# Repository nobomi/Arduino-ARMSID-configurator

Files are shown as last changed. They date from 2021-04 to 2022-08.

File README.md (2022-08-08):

# Arduino ARMSID configurator

Simple Arduino shield with a sketch for ARMSID and ARM2SID configuration using Tera Term or similar ANSI terminal program. It allows:

- configure ARMSID or ARM2SID parameters (SID type, address mappings, filters, digifix, ...)
- update ARMSID or ARM2SID firmware
- play some SIDs to a 3.5 mm stereo audio jack (more than 60 ohms headphones or line input connection only)

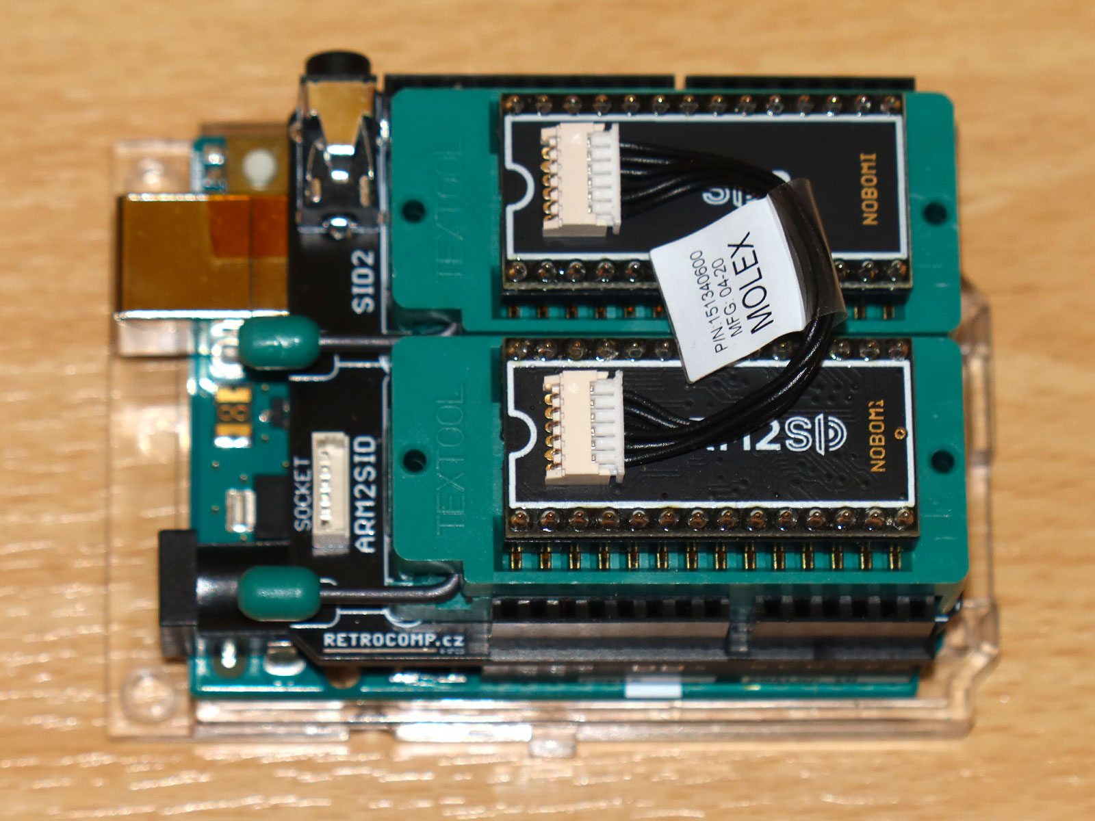
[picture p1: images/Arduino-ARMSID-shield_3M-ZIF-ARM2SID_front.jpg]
Arduino ARMSID configurator shield with 3M ZIF sockets
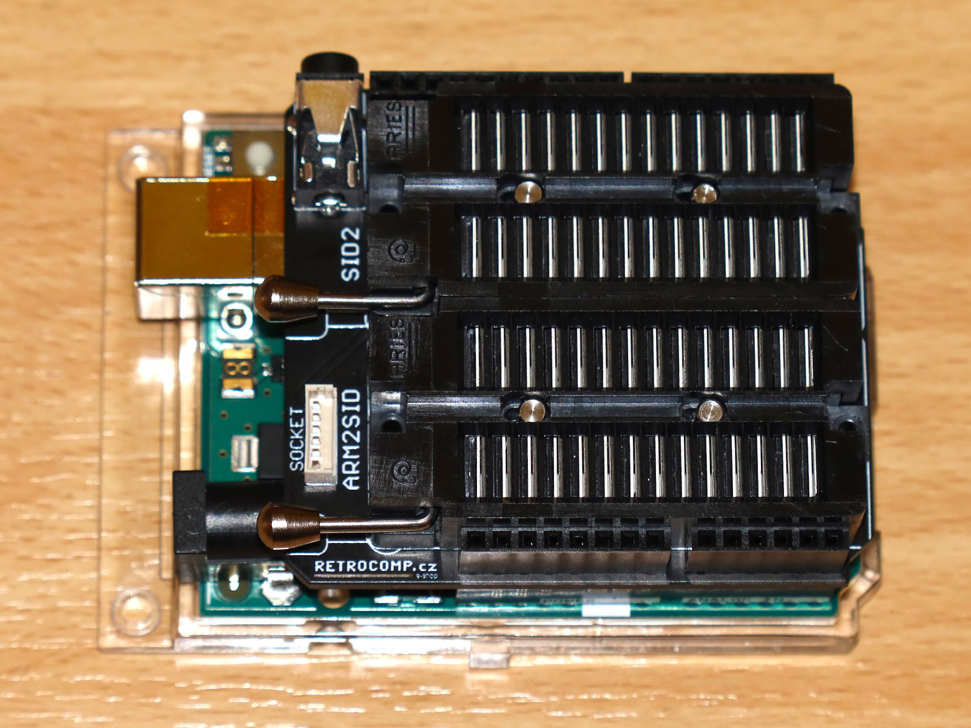
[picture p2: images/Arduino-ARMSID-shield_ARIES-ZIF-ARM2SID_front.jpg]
Arduino ARMSID configurator shield with ARIES ZIF sockets
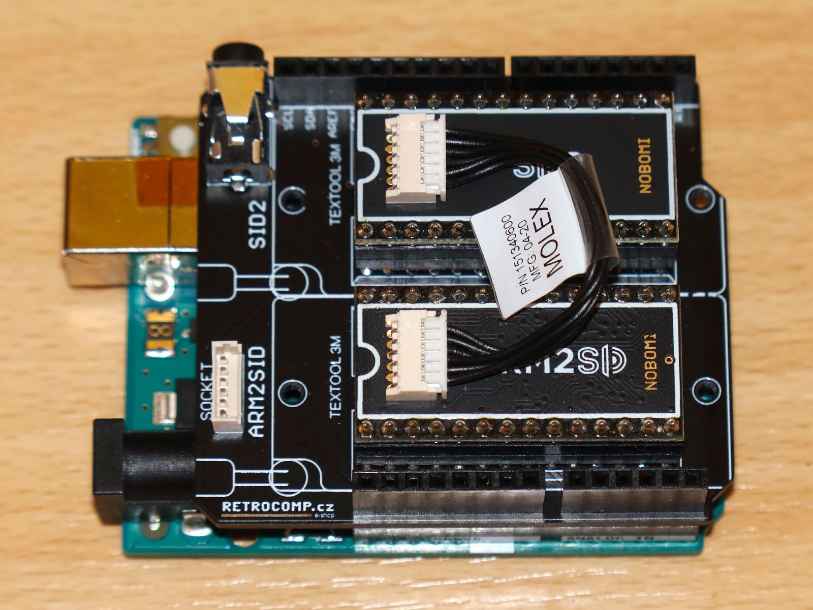
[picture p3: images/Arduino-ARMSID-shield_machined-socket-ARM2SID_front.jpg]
Arduino ARMSID configurator shield with machined sockets
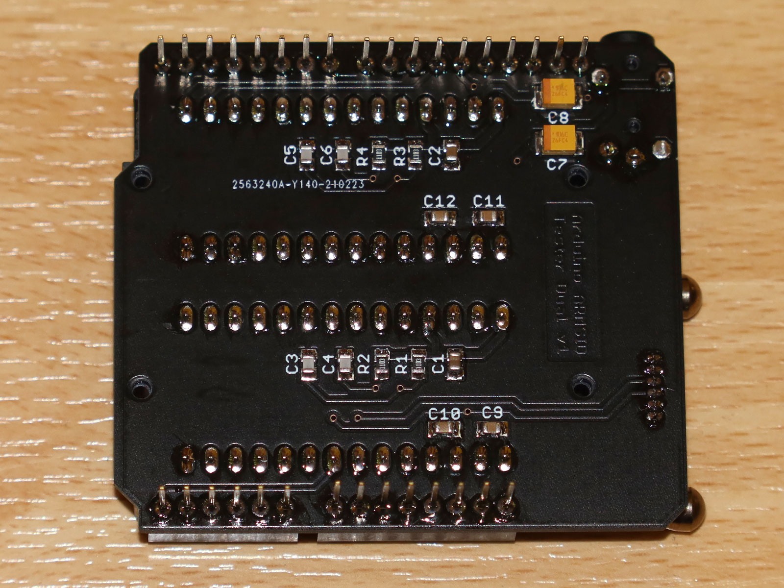
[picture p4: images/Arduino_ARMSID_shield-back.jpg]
Arduino ARMSID configurator shield from back side
&nbsp;&nbsp;&nbsp;&nbsp;&nbsp;&nbsp;

#### ANSI terminal (Tera Term) configuration screen samples

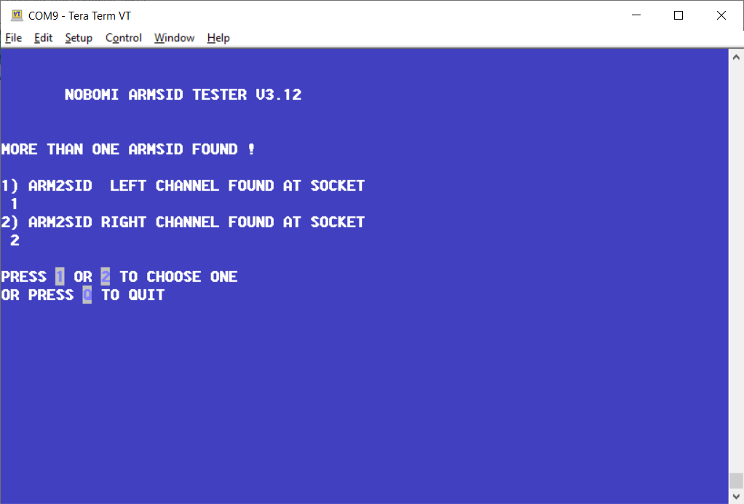
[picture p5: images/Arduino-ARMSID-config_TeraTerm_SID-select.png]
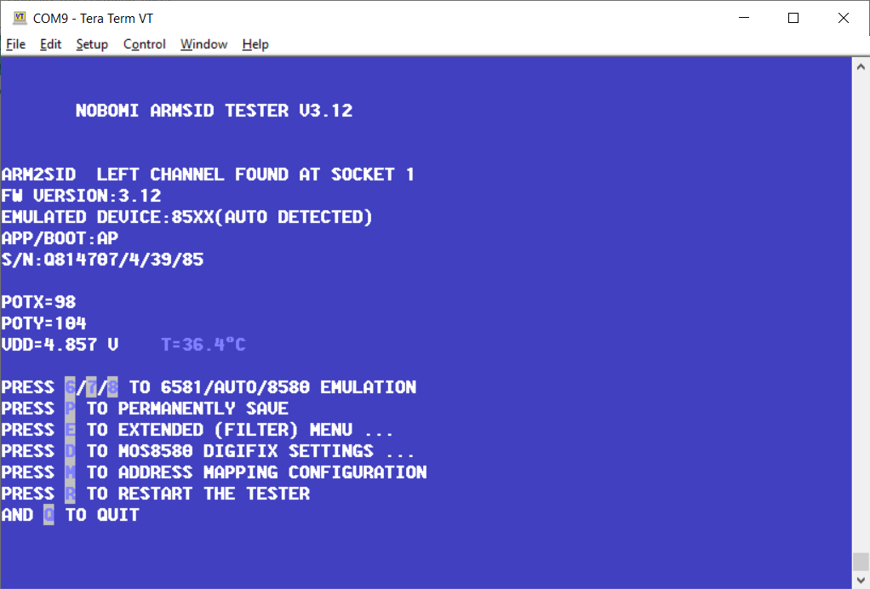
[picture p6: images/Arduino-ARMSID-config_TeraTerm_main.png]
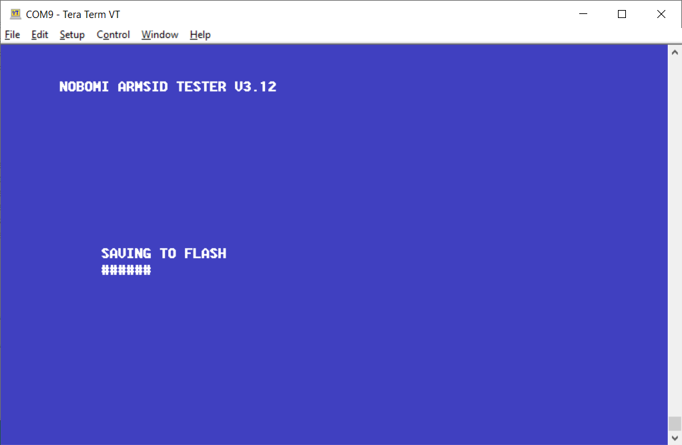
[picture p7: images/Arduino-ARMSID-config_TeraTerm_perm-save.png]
&nbsp;&nbsp;&nbsp;&nbsp;

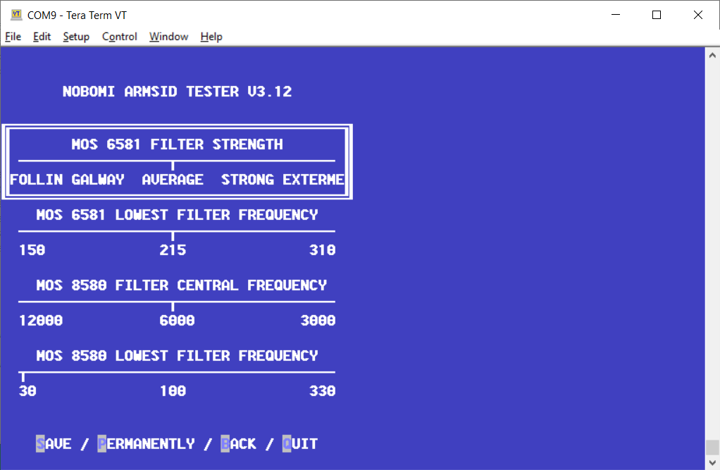
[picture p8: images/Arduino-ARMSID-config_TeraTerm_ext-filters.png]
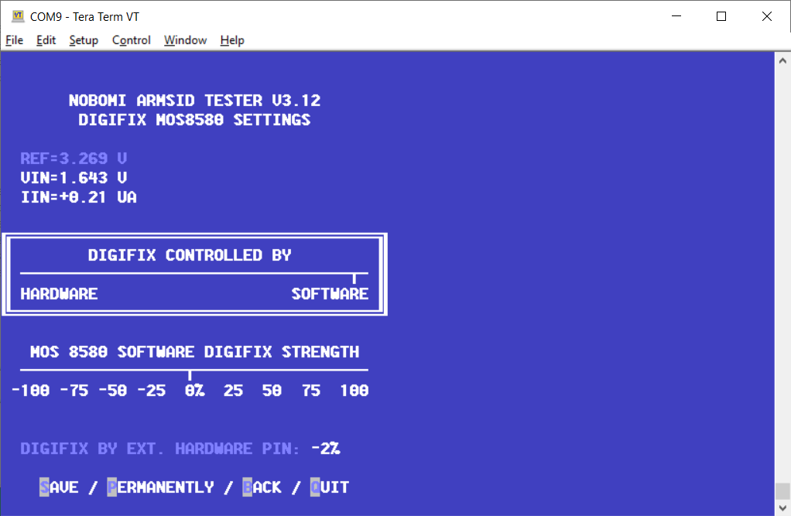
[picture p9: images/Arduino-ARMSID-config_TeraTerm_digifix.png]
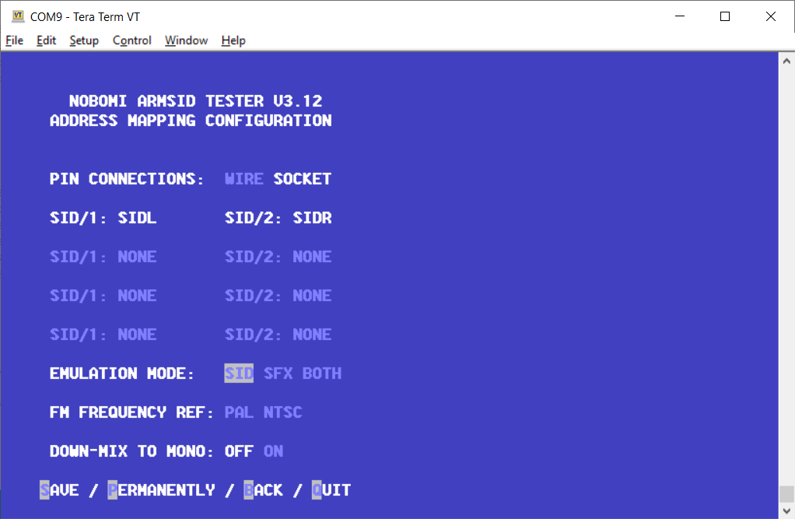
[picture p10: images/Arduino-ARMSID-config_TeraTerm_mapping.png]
&nbsp;&nbsp;&nbsp;&nbsp;

### Schematic and PCB Layout

[Schematic](PCB/Arduino_AMRSID_tester_dual_sch.pdf)

[PCB Layout - Gerber files](PCB/Gerber/Arduino_AMRSID_tester_dual_Gerber.zip)

### Connectors

#### ARM2SID

Main DIL28 socket for ARMSID or ARM2SID to be configured.

#### SID2

DIL28 socket for the 2nd ARMSID or SID2 (ARM2SID). When using SID2, please use 6-pin PicoBlade connector with 5 cm wire to connect SID2 to ARM2SID.  

#### AUDIO1

Stereo audio output for headphones or amplifier line input.

Pin | Description     
--- | ---------------
Tip (the inner outer contact) | Output: Audio left (>60 ohms or line level)
Second row (the inner middle contact) | Output: Audio right (>60 ohms or line level)
Ring / Sleeve         |	Ground (GND)

Note: When connecting headphones, the impedance should be at least 60 ohm.
Note2: Shorten the connector legs near the board edge to not exceed the hole before soldering. Solder without creating solder (tin) bump, clean and cover with Kapton tape, as it could conflict with Arduino USB connector otherwise.

#### SOCKET (53047-06)

6-pin MOLEX PicoBlade connector for ARM2SID 2nd SID connection. Use 10 cm 6-pin PicoBlade connectors wire to ARM2SID instead of populating SID2 socket. 

Pin | Description     
--- | ---------------
1 | GND
2 | GND
3 |	Output: R/W (R/W signal for the 2nd socket)
4 |	Output: CS2 (CS signal for the 2nd socket)
5 | GND
6 | Input: Audio right

#### Arduino

Arduino pin headers used to connect to Arduino UNO. Only models with ATmega328P should be used, such as **Arduino UNO Rev3** or **Arduino UNO Rev3 SMD**.

### Bill of Materials

Component type | Reference         | Description                                | Quantity | Possible sources           | Notes
-------------- | ----------------- | ------------------------------------------ | -------- | -------------------------- | --------
PCB            |                   | Arduino ARMSID configurator shield PCB     | 1        | Order PCB or parts kit at [Retrocomp.cz e-shop](https://www.retrocomp.cz) or order from a PCB manufacturer of your choice using provided Gerber or Eagle files |  
Resistor       | R1, R2, R3, R4    | 110 kohm, SMD 0805                         | 4        | Digikey [RMCF0805FT110KCT-ND](https://www.digikey.com/product-detail/en/stackpole-electronics-inc/RMCF0805FT110K/RMCF0805FT110KCT-ND/2418241) | Needed only if you want to test POT inputs  
Capacitor      | C1, C2            | 100 nF, SMD 0805                           | 2        | Digikey [490-11955-1-ND](https://www.digikey.com/product-detail/en/murata-electronics/GCD21BR71H104KA01L/490-11955-1-ND/5403192) |  
Capacitor      | C3, C4, C5, C6    | 2.2 nF, SMD 0805                           | 4        | Digikey [490-6448-1-ND](https://www.digikey.com/product-detail/en/murata-electronics/GRM2165C2A222JA01D/490-6448-1-ND/3845645) | Needed only if you want to test POT inputs  
Capacitor      | C7, C8            | 10 uF, SMD 3528                            | 2        | Digikey [478-4975-1-ND](https://www.digikey.com/product-detail/en/avx-corporation/TPSB106M016R0800/478-4975-1-ND/1888186)      | Needed only if you want to use stereo audio output     
Capacitor      | C9, C10, C11, C12 | 15 nF, SMD 0805                            | 4        | Digikey [490-5718-1-ND](https://www.digikey.com/product-detail/en/murata-electronics/GR321AD72E153KW01D/490-5718-1-ND/2712261) | Needed only if you plan to use real SIDs (no sufficient power provided for real SIDs on current design)  
DIP/DIL Socket | ARM2SID, SID2     | 28 pin DIL socket (preferably ZIF)         | 2        | Digikey [3M2802-ND](https://www.digikey.cz/product-detail/cs/3m/228-1277-00-0602J/3M2802-ND/95268) or [A302-ND](https://www.digikey.cz/product-detail/cs/aries-electronics/28-6554-10/A302-ND/27592)  | The second (SID2) DIL socket si needed only for the ARM2SID's 2nd SID configuration and can be substitued by 10 cm 6-pin PicoBlade wire to the SOCKET connector.
Connector      | AUDIO1            | Audio connector JACK 3.5 mm - type FC68125 | 1        | Farnell [2309468](https://cz.farnell.com/cliff-electronic-components/fc68125/connector-phono-3-5mm-jack-4pole/dp/2309468)      | Needed only if you want to use stereo audio output  
Connector      | SOCKET            | Molex PicoBlade 6-pin vertical header      | 1        | Digikey [WM1735-ND](https://www.digikey.com/product-detail/en/molex/0530470610/WM1735-ND/242857)                               | Needed only if you want connect ARM2SID to board without SID2  
Connector      | B1                | Arduino stackable header kit               | 1        | Digikey [1568-1413-ND](https://www.digikey.com/product-detail/en/sparkfun-electronics/PRT-11417/1568-1413-ND/6161755)          |  
Arduino        | B1                | Arduino UNO Rev3                           | 1        | Digikey [1050-1041-ND](https://www.digikey.com/product-detail/end/arduino/A000073/1050-1041-ND/3476357) or [1050-1024-ND](https://www.digikey.com/product-detail/en/arduino/A000066/1050-1024-ND/2784006) |   

## Known Issues
* Version 1.0
  * 3.5 mm audio JACK touches the Arduino USB connector. Solder without tin bump and isolate with Kapton tape!
  * No power supply for real SIDs. The 5V provided is not sufficient for MOS 6581 nor 8580.  

## Guide
DARRELL A. WESTBURY created nice guide for configuring and updating ARMSID/ARM2SID using Arduino shield [GET IT HERE](https://docs.google.com/document/d/1B_xzXlLjq3NbKnOrhIoJ5PrlVIhlsD_aASEhB0CWK90/edit?usp=sharing). He also shared his experience with setup and using ARM2SID in MB6582. Thank you!

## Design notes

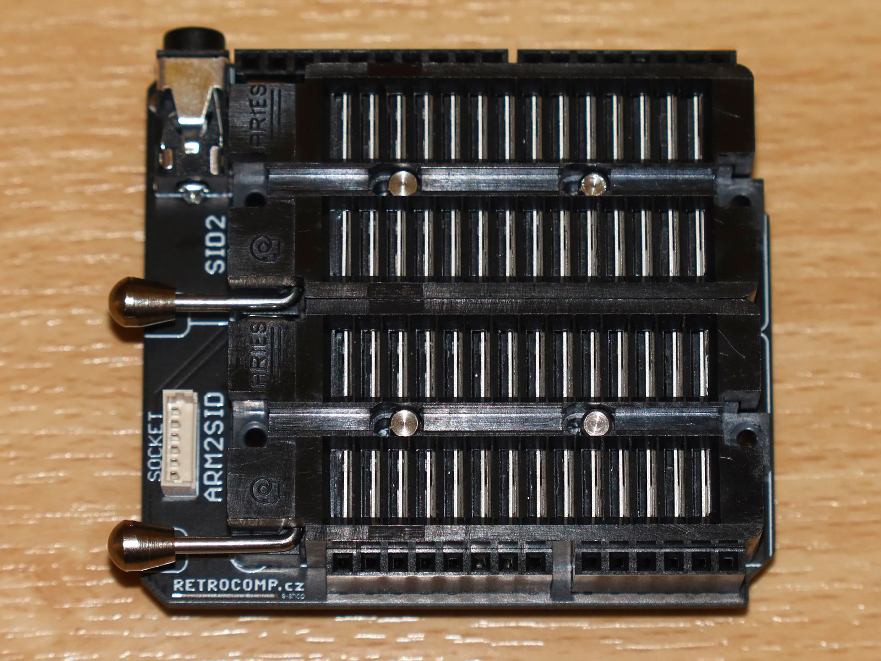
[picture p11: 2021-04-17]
images/Arduino_ARMSID_shield-front.jpg

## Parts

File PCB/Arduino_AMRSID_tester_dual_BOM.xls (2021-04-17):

Arduino ARMSID tester
Qty | Parts | Value | Device | Package | Description
2 | ARM2SID, SID2 | 228-1277-00-0602J | 228-1277-00-0602J | 228-1277-00-0602J | Zero Insertion Force Socked
1 | AUDIO1 | FC68125 | FC68125 | FC68125 | Audio connector JACK 3.5mm - 4 POL ( TME - type FC68125 )
1 | B1 | Arduino UNO | ARDUINO_UNO_R3_SHIELDBASIC | UNO_R3_SHIELD | Arduino R3 Shield Footprint
2 | C1, C2 | 100n | C-EUC0805K | C0805K | CAPACITOR, European symbol
4 | C3, C4, C5, C6 | 2n2 | C-EUC0805K | C0805K | CAPACITOR, European symbol
2 | C7, C8 | 10u | CPOL-EUB/3528-21R | B/3528-21R | POLARIZED CAPACITOR, European symbol
4 | C9, C10, C11, C12 | n.c. | C-EUC0805K | C0805K | CAPACITOR, European symbol
4 | R1, R2, R3, R4 | 110k | R-EU_R0805 | R0805 | RESISTOR, European symbol
1 | SOCKET | 53047-06 | 53047-06 | 53047-06 | CONNECTOR Molex 0530470610
1 | PCB

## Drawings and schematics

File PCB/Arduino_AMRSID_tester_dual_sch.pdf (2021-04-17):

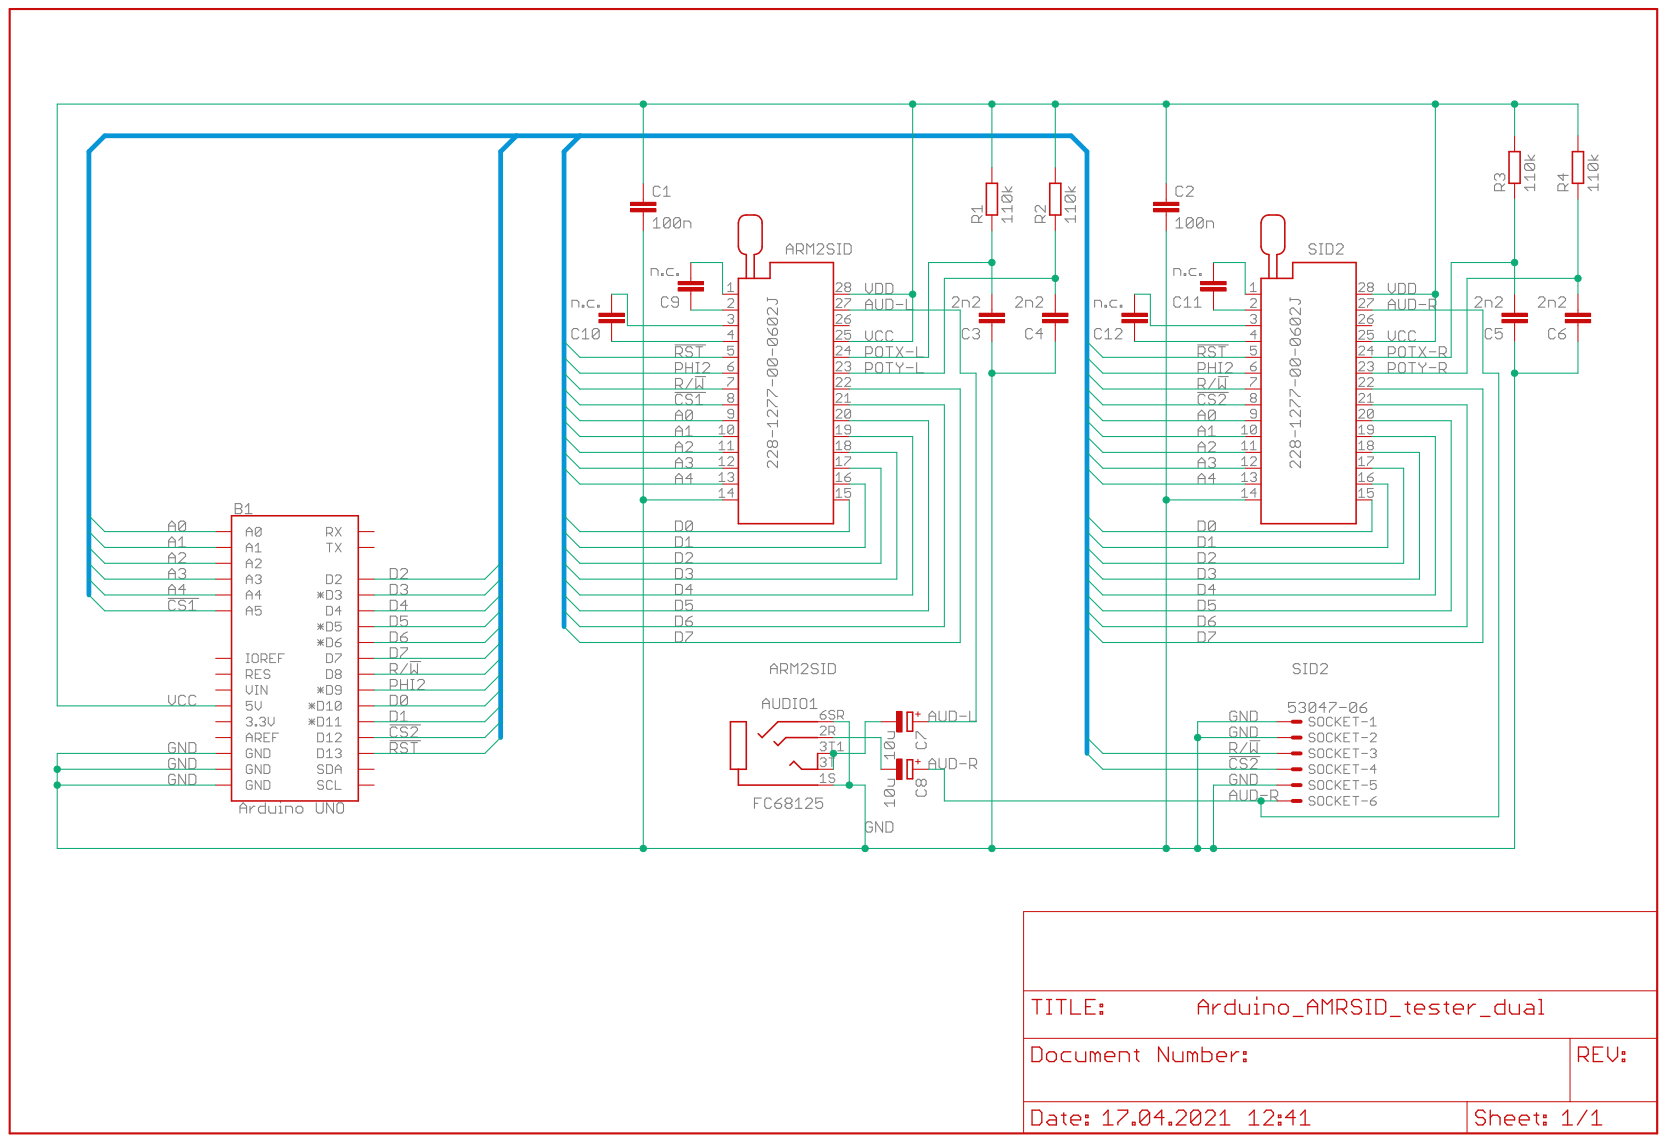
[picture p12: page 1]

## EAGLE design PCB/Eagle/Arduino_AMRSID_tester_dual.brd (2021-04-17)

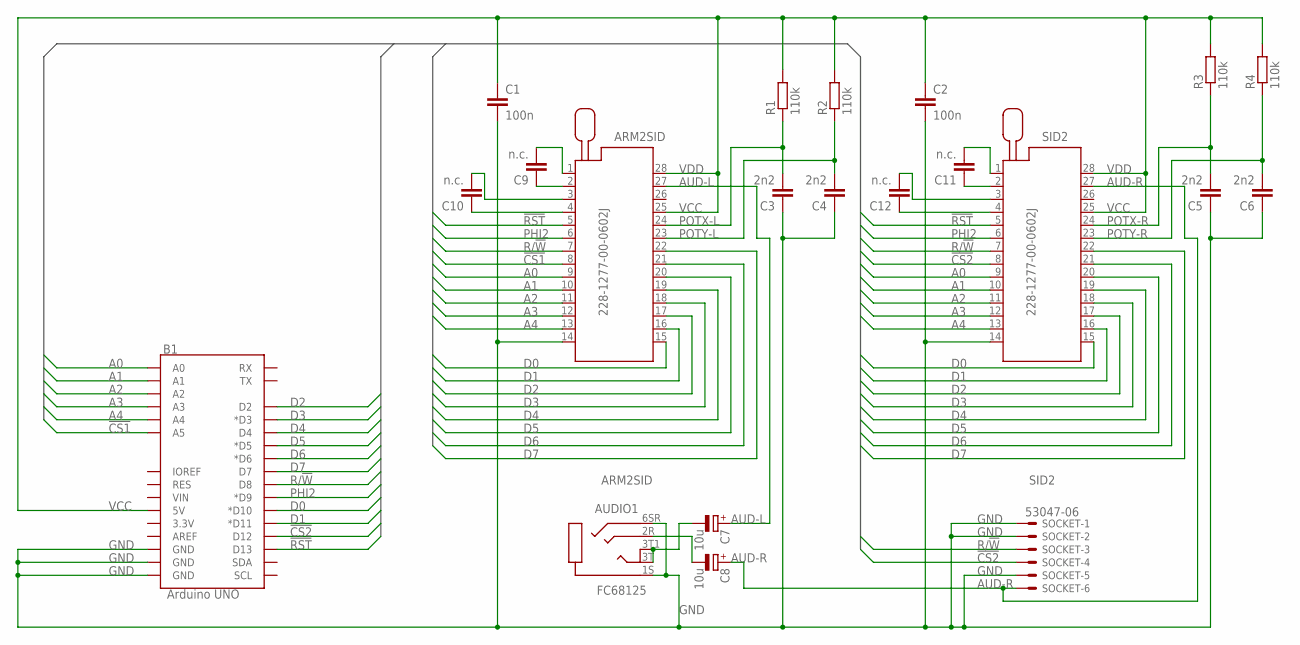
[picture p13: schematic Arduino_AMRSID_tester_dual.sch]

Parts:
ARM2SID: 228-1277-00-0602J
AUDIO1: FC68125
B1: Arduino UNO; UNO_R3_SHIELD
C1, C2: 100n; C0805K
C3, C4, C5, C6: 2n2; C0805K
C7, C8: 10u; B/3528-21R
C9, C10, C11, C12: n.c.; C0805K
R1, R2, R3, R4: 110k; R0805
SID2: 228-1277-00-0602J
SOCKET: 53047-06

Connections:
!CS1: ARM2SID.8, B1.A5
!CS2: B1.D12, SID2.8, SOCKET.4
!RST: ARM2SID.5, B1.D13, SID2.5
A0: ARM2SID.9, B1.A0, SID2.9
A1: ARM2SID.10, B1.A1, SID2.10
A2: ARM2SID.11, B1.A2, SID2.11
A3: ARM2SID.12, B1.A3, SID2.12
A4: ARM2SID.13, B1.A4, SID2.13
AUD-L: ARM2SID.27, C7.+
AUD-R: C8.+, SID2.27, SOCKET.6
D0: ARM2SID.15, B1.D10 (*D10), SID2.15
D1: ARM2SID.16, B1.D11 (*D11), SID2.16
D2: ARM2SID.17, B1.D2, SID2.17
D3: ARM2SID.18, B1.D3 (*D3), SID2.18
D4: ARM2SID.19, B1.D4, SID2.19
D5: ARM2SID.20, B1.D5 (*D5), SID2.20
D6: ARM2SID.21, B1.D6 (*D6), SID2.21
D7: ARM2SID.22, B1.D7, SID2.22
GND: ARM2SID.14, AUDIO1.1S, AUDIO1.6SR, B1.GND@0 (GND), B1.GND@1 (GND), B1.GND@2 (GND), C1.2, C2.2, C3.1, C4.1, C5.1, C6.1, SID2.14, SOCKET.1, SOCKET.2, SOCKET.5
unnamed: AUDIO1.2R, C8.-
unnamed: ARM2SID.2, C9.1
unnamed: AUDIO1.3T, AUDIO1.3T1, C7.-
unnamed: ARM2SID.1, C9.2
unnamed: C11.1, SID2.2
unnamed: C11.2, SID2.1
unnamed: ARM2SID.4, C10.1
unnamed: ARM2SID.3, C10.2
unnamed: C12.1, SID2.4
unnamed: C12.2, SID2.3
PHI2: ARM2SID.6, B1.D9 (*D9), SID2.6
POTX-L: ARM2SID.24, C3.2, R1.1
POTX-R: C5.2, R3.1, SID2.24
POTY-L: ARM2SID.23, C4.2, R2.1
POTY-R: C6.2, R4.1, SID2.23
R/!W: ARM2SID.7, B1.D8, SID2.7, SOCKET.3
VCC: ARM2SID.25, ARM2SID.28, B1.5V, C1.1, C2.1, R1.2, R2.2, R3.2, R4.2, SID2.25, SID2.28

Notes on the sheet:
ARM2SID
SID2
VDD

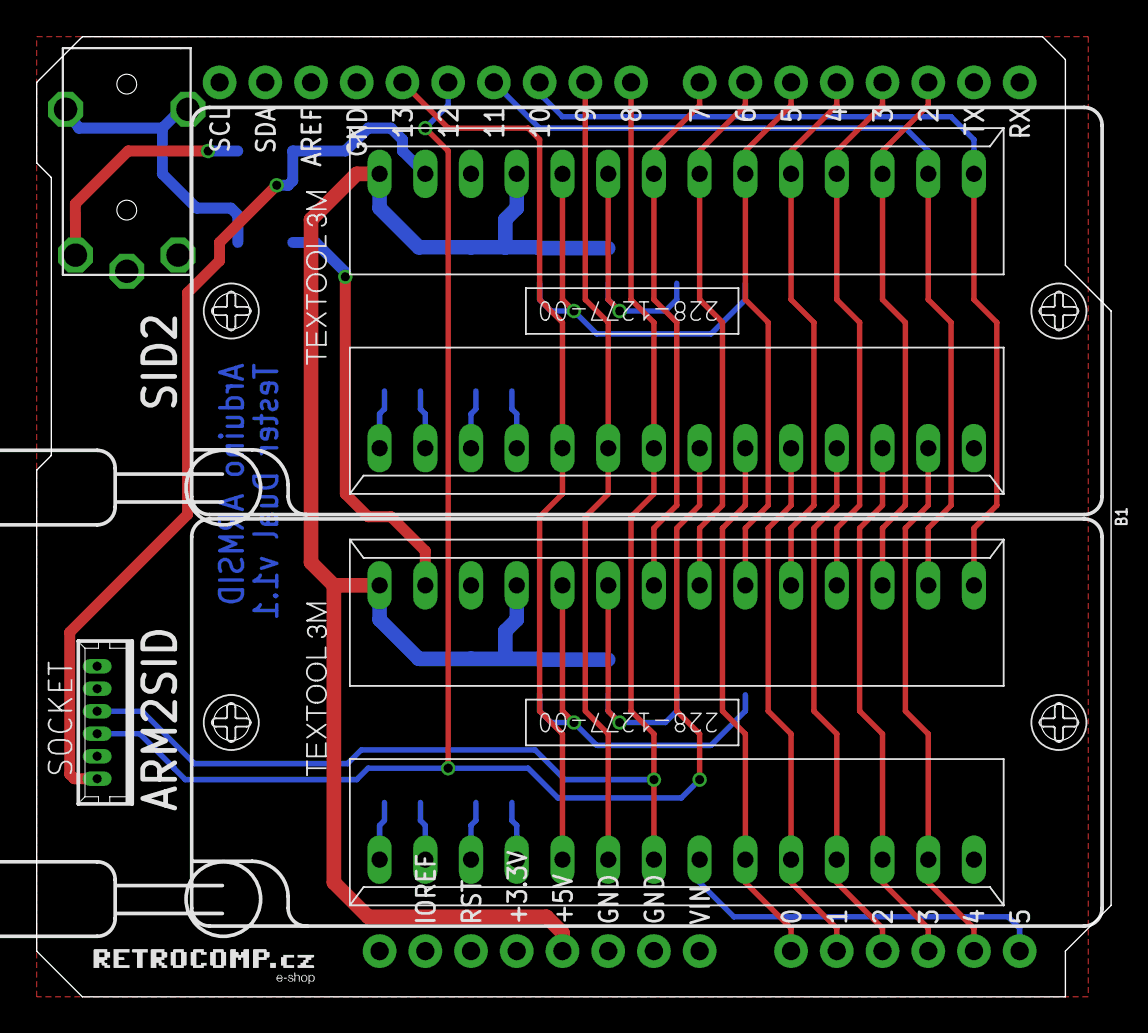
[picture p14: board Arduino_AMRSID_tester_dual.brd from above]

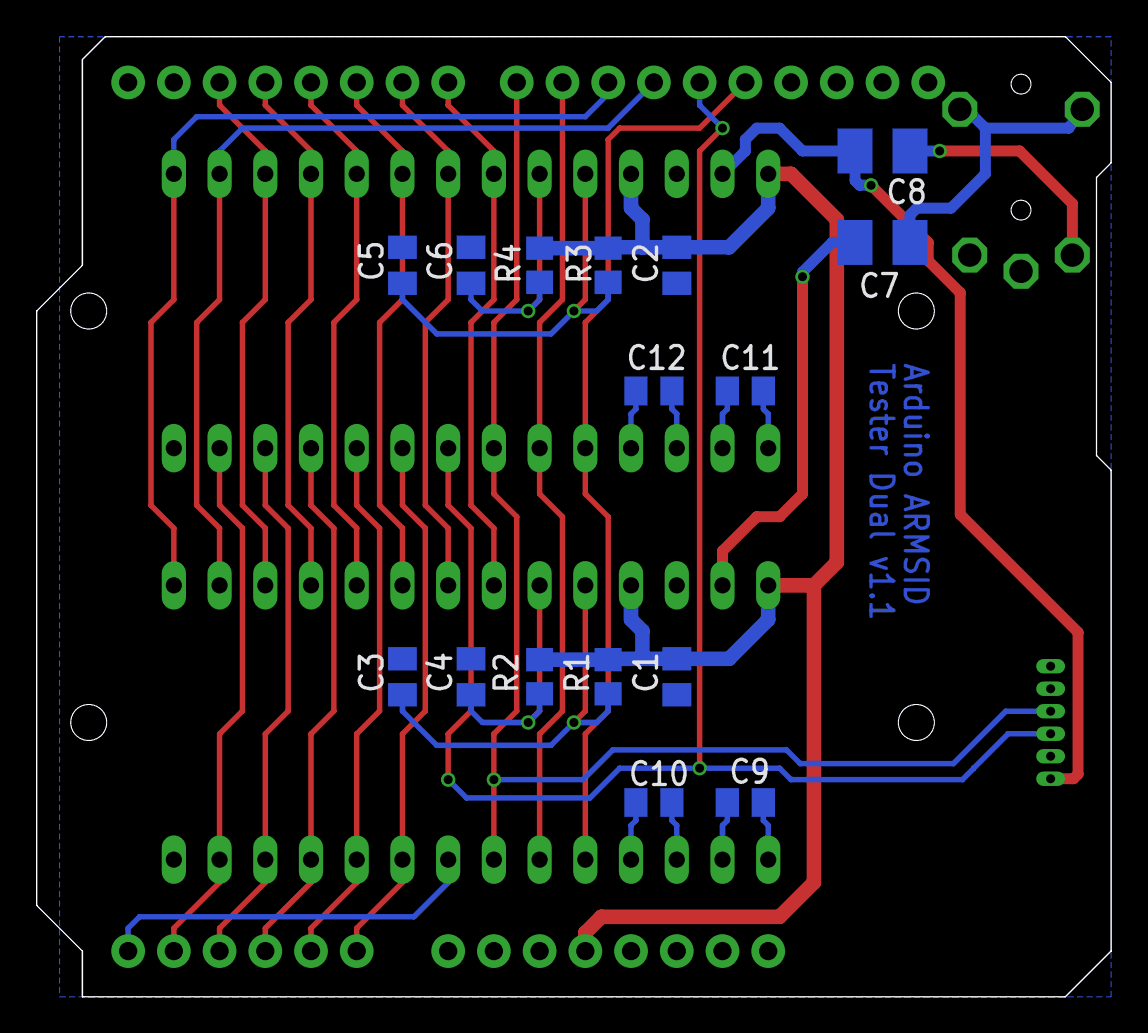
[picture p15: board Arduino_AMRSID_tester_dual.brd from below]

Board: 4 copper layers, 59.7 x 53.3 mm, 21 parts (16 on the bottom side), 36 nets.

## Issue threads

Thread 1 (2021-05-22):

User guide for FWUpdate and SIDPlayer

dwestbury, 2021-05-22:
My ARMSID Arduino Shield arrived today and I just finished the build.
> So far ARMSID_Test works pretty much as expected, with a simple enough menu system, but there are tons of "?" in the frames / borders of some of the menus, which make them a bit difficult to read? Perhaps I should use a different font?

> After flashing the FW_Updater sketch to my UNO, I haven't been able to figure out how to get this to work? I don't seem to be able to login from a terminal or see any serial monitor output from the Arduino IDE?

> Likewise the ArduinoPlay sketch doesn't seem to do much, except play a short couple notes from the left audio channel. Is there more to this?

> Finally, I tried using SIDPlay410.exe from a windows system, but wasn't able to get any audible sound?

I'm thinking a users guide for these utilities would be super useful....

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

mlukasek, 2021-05-22:
You must use ANSI terminal client, Try tu use TeraTerm to get correct output.

The updater needs Arduion firmware + run PC updater form command line:
ARMSIDupArduino.exe COMport updatebinary.bin
where COMport is you Arduino COM port, eg. COM5 and updatebinary.bin is special updater binary. There is no need to update now, as you should have the latest version.

The SID player is mostly a proof of concept. It plays only rom RSID files, It is similar as the updater. You have to upload ArduinoPlay.ino to your Arduino and then run on PC command line:
SIDplay410.exe COMport SIDFile.sid
where COMport is your COM port, eg. COM4 and SIDfile.sid is SID file to play, eg. included Hexadecimal_2SID.sid

dwestbury, 2021-05-23:
@mlukasek Thanks for the info... I had thought that I could access the Arduino via a terminal, once the FW sketch was compiled and written. I didn't realize the PC program was needed. Will try this again to confirm it's working for me.

WRT the SID Player, I flashed the Arduino sketch, then attempted to run the PC SIDPlay410.exe as outlined, but this only gave me some odd beeps? No actual music.

Great job on this BTW  - I really think this is a cool project that will attract DIY builders from MIDIBox, SIDBlaster, SID Guts and various other projects, to consider ARMSID/ARM2SID, now that they won't need a working C64 to configure the sound they're after.

Cheers

pda, 2021-08-25:
> I attempted to run the PC SIDPlay410.exe as outlined (see earlier screenshot above), but this only gave me some odd beeps? No actual music? Guess I'm doing something wrong here?

The sketch itself plays four beeps (2kHz 1kHz 1kHz 3kHz) on startup, including on serial port connect/disconnect:
https://github.com/nobomi/Arduino-ARMSID-configurator/blob/main/Arduino/StereoSIDPlayer/ArduinoPlay/ArduinoPlay.ino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

Is that the only sound you're hearing?

I ask because I started porting the Windows code to macOS/unix, and I'm hearing those startup beeps, but then when the `.sid` starts streaming I hear a glitchy jumble of SID sounds with lots of silence in between. It's almost certainly because of something I've done wrong in the work-in-progress port of the serial port code, but if you were hearing the same from the unmodified Windows code that would be useful information.

mlukasek, 2021-08-25:
After you reset the Arduino, it should make the beeps as you stated. When you start the player, it should play. I created short video on my PC and put it in video folder. There is Arduino reset on the beginning and then command to play from system prompt and a part of demo SID. Not all SID files will play. It is mostly some proof of concept, the shiled is not meant as a player.

pda, 2021-08-25:
Thanks @mlukasek. I got a Windows machine up and running today and confirmed that it works perfectly there, so the problem is my own macOS/unix code in #2. So, my comment isn't related to this thread. But it's cool to have the video for other people 👌

mlukasek, 2021-08-25:
> WRT the SID Player, after flashing the correct sketch, I attempted to run the PC SIDPlay410.exe as outlined (see earlier screenshot above), but this only gave me some odd beeps? No actual music? Guess I'm doing something wrong here?

@dwestbury Did you manage to get it work? It looks like a communication trouble on your screnshot. There should mostly be more dots between fo....fo......fo..fo......fo, check my newly uploaded video. Maybe communication interface speed? Did you change the speed in Serialn.begin() in setup() of your ArduinoPlay.ino ?

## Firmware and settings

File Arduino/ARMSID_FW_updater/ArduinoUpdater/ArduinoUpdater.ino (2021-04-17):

/*
** Arduino ARMSID Updater
** 
** Copyright (c) 2021 nobomi (Bohumil Novacek, dzin@post.cz)
** 
** MIT License
** 
** Permission is hereby granted, free of charge, to any person obtaining a copy
** of this software and associated documentation files (the "Software"), to deal
** in the Software without restriction, including without limitation the rights
** to use, copy, modify, merge, publish, distribute, sublicense, and/or sell
** copies of the Software, and to permit persons to whom the Software is
** furnished to do so, subject to the following conditions:
** 
** The above copyright notice and this permission notice shall be included in all
** copies or substantial portions of the Software.
** 
** THE SOFTWARE IS PROVIDED "AS IS", WITHOUT WARRANTY OF ANY KIND, EXPRESS OR
** IMPLIED, INCLUDING BUT NOT LIMITED TO THE WARRANTIES OF MERCHANTABILITY,
** FITNESS FOR A PARTICULAR PURPOSE AND NONINFRINGEMENT. IN NO EVENT SHALL THE
** AUTHORS OR COPYRIGHT HOLDERS BE LIABLE FOR ANY CLAIM, DAMAGES OR OTHER
** LIABILITY, WHETHER IN AN ACTION OF CONTRACT, TORT OR OTHERWISE, ARISING FROM,
** OUT OF OR IN CONNECTION WITH THE SOFTWARE OR THE USE OR OTHER DEALINGS IN THE
** SOFTWARE.
*/


/*****************************************************************************/
/*                                   Code                                    */
/*****************************************************************************/

// ----------------------------- arduino setup ---------------------------------

#define PHI2 9
#define RW 8
#define CS1 A5
#define CS2 12
#define RST 13 // together with Arduino UNO LED
#define D1 11
#define D0 10

void Set_PHI2_1MHz() {
  TCCR1A = 0b01000000;
  TCCR1B = 0b00001001;
  OCR1AH = 0;
  OCR1AL = 7; // 1 MHz
  TIMSK1 = 0;
}

void setup() {
  init();
  // put your setup code here, to run once:
  PORTD = B00000000;
  PORTB = B00110000; // bit 5 RST HIGH, bit 4 CS2 HIGH, bit 0 R/W LOW
  PORTC = B00100000; // no pullups, but pin 5 CS1 HIGH
  DDRD = B11111111; // digital pins 2-7 output (data)
  DDRB = B11111111; // didigtal pins 10-11 output (data)
  DDRC = B00111111; // analog pins 0-4 output (register address), bit 5 CS
  Set_PHI2_1MHz();
  Serial.begin(115200);
}

void reset_SID() {
  digitalWrite(RST, LOW);
  delay(10);
  digitalWrite(RST, HIGH);
  delay(750);
}

// ----------------------------- IO operations ---------------------------------

byte SIDrd(byte addr) {
  byte pd, pb;
  // TCCR1B = 0b00001000;
  DDRD = DDRD & B00000011; // digital pins 2-7 input (data)
  DDRB = DDRB & B11110011; // didigtal pins 10-11 input (data)
  PORTD = PORTD & B00000000; // no pullups on data digital pins 2-7
  PORTB = PORTB & B11110011; // no pullups on data digital pins 10-11
  PORTB = PORTB | B00000001; // RW HIGH
  PORTC = (addr&31) | B00100000; // set address, keep CS HIGH
  if (addr>=32) {
    register byte cs = PORTB & ~(B00010000); // CS2 LOW
    while (PINB&2);
    while ((PINB&2)==0);
    PORTB = cs;
  }
  else {
    register byte cs = addr & B00011111; // write address and CS LOW
    while (PINB&2);
    while ((PINB&2)==0);
    PORTC = cs;
  }
  while (PINB&2);
  while ((PINB&2)==0);
  pd = PIND;
  pb = PINB;
  if (addr>=32) PORTB |= B00010000; // CS2 HIGH
  else PORTC = PORTC | B00100000; // CS HIGH
  byte out = (pd & B11111100) | ((pb >> 2) & B00000011);
  PORTB = PORTB & B11111110; // RW LOW
  DDRD = DDRD | B11111100; // digital pins 2-7 output (data)
  DDRB = DDRB | B00001100; // didigtal pins 10-11 output (data)
  // TCCR1B = 0b00001001;
  return out;
}

void SIDwr(byte addr, byte dta) {
  // TCCR1B = 0b00001000;
  PORTD = dta & B11111100;
  PORTB = (PORTB & B11110011) | ((dta & B00000011) << 2);
  PORTC = (addr&31) | B00100000; // set address, keep CS HIGH
  if (addr>=64) {
    register byte csb = PORTB & ~(B00010000); // CS2 LOW
    register byte csc = addr & B00011111; // write address and CS LOW
    while (PINB&2);
    while ((PINB&2)==0);
    PORTC = csc;
    PORTB = csb;
  } else if (addr>=32) {
    register byte cs = PORTB & ~(B00010000); // CS2 LOW
    while (PINB&2);
    while ((PINB&2)==0);
    PORTB = cs;
  }
  else {
    register byte cs = addr & B00011111; // write address and CS LOW
    while (PINB&2);
    while ((PINB&2)==0);
    PORTC = cs;
  }
  while (PINB&2);
  while ((PINB&2)==0);
  if (addr>=64) {
    PORTC = PORTC | B00100000; // CS HIGH
    PORTB |= B00010000; // CS2 HIGH
  }
  else if (addr>=32) PORTB |= B00010000; // CS2 HIGH
  else PORTC = PORTC | B00100000; // CS HIGH
  return;
}

/*void SIDwr2(byte addr, byte dta) {
  if (addr&64) {
    SIDwr(addr&31,dta);
    SIDwr(addr|32,dta);
  } else SIDwr(addr,dta);
}*/

////////////////////////////////////////////////////////////////////////////////

//static char ison=1;
//
//void Xoff(void) {
//  if (ison==1) Serial.write(0x13);
//  ison=0;
//}

//void Xon(void) {
//  if (ison==0) Serial.write(0x11);
//  ison=1;
//}

void wait16(void) {
  char i;
  for(i=0;i<16;i++) {
    while (PINB&2);
    while ((PINB&2)==0);
  }
}

void nosound(void) {
  int i;
  wait16();
  for(i=0;i<16;i++) SIDwr(i,0);
  wait16();
  for(i=0;i<32;i++) SIDwr(i,0);
  wait16();
  for(i=0;i<48;i++) SIDwr(i,0);
  wait16();
  for(i=0;i<64;i++) SIDwr(i,0);
  wait16();
}

////////////////////////////////////////////////////////////////////////////////

static unsigned long us=0;

#define T1khz  16777U
#define T2khz (16777U*2U)
#define T3khz (16777U*3U)

void tone(unsigned short i) {
  SIDwr(0+14,i);
  SIDwr(1+14,i>>8);
  SIDwr(4+14,17);
  delay(200);
  SIDwr(4+14,16);
  delay(300);
}

static void  measure() {
  unsigned char i;
    tone(T2khz);
    tone(T1khz);
    tone(T1khz);
    tone(T3khz);
}

void play() {
    SIDwr(0,255);
    SIDwr(1,255);
    SIDwr(6,240);
    SIDwr(6+14,240);
    SIDwr(23,0xF1); //1ch filter
    SIDwr(24,0x0F); //volume
    measure();
}

static byte rx_buf[1024];
static int rx_top=0;
static int rx_bottom=0;

int rx_push(byte val) {
  int rx_next=(rx_top+1)&1023;
  if (rx_next!=rx_bottom) {
    rx_buf[rx_top]=val;
    rx_top=rx_next;
  }
}

byte rx_pop() {
  if (rx_top!=rx_bottom) {
    byte res=rx_buf[rx_bottom];
    rx_bottom=(rx_bottom+1)&1023;
    return res;
  }
  return 0;
}

int rx_push_all() {
  int i=Serial.available();
  while (i>0) {
    rx_push(Serial.read());
    i--;
  }
}

void rx_pop4(byte *b) {
  *b++=rx_pop();
  *b++=rx_pop();
  *b++=rx_pop();
  *b=rx_pop();
}

int rx_cnt() {
  return (rx_top-rx_bottom)&1023;
}

unsigned char nibbletoc(unsigned char s) {
  unsigned char res=0;
  switch (s) {
    case '0'...'9':res=s-'0';break;
    case 'A'...'F':res=s-'A'+10;break;
    case 'a'...'f':res=s-'a'+10;break;
    default: break;
  }
  return res;
}

unsigned char hextoc(unsigned char *s) {
  return (nibbletoc(s[0])<<4) + nibbletoc(s[1]);
}

int main(void)
{
  int i=0;
  unsigned char b[10];
  init();
  setup();
  reset_SID();
  nosound();
  play();
  nosound();
  while (1) {
//    rx_push_all();
//    rx_pop();
//    if (rx_cnt()>0) {
    if (Serial.available()) {
//      unsigned char c=rx_pop();
      unsigned char c=Serial.read();
      if (c<32) {
        if (b[0]=='W' && i>=5) {
          SIDwr(hextoc(&b[1]), hextoc(&b[3]));
        }
        else if (b[0]=='R' && i>=3) {
          Serial.write(SIDrd(hextoc(&b[1])));
        }
        i=0;
      } else if (i<10) b[i++]=c;
      //Serial.write(c);
    }
  }
  return 0;
}

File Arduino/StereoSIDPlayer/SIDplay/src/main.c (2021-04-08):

#define CHIPS_IMPL
#include "m6502.h"
#include <stdint.h>
#include <stdio.h>
#include <fcntl.h>
#include <windows.h>
#include <time.h> // clock_t, clock, CLOCKS_PER_SEC
#include <conio.h>

void delay(unsigned int milliseconds){

    clock_t start = clock();

    while((clock() - start) * 1000 / CLOCKS_PER_SEC < milliseconds);
}

HANDLE hSerial;

static int stereo=0;
static int state_on=1;

void serout(unsigned char *data, int len) {
    DWORD bytes_written;
    //printf("serout\n");
    do {
        char x;
        ReadFile(hSerial, &x, 1, &bytes_written, NULL);
        if (bytes_written>0) {
            if (x==0x11) {
                    state_on=1;
                    printf("o");
            }
            if (x==0x13) {
                    state_on=0;
                    printf("f");
            }
        }
    }
    while (bytes_written>0 || state_on==0);
    if(!WriteFile(hSerial, data, len, &bytes_written, NULL))
    {
        fprintf(stderr, "Error\n");
        CloseHandle(hSerial);
        exit(1);
    }
}

int __ssat(int a,int b) {
    if (a<-((1<<(b-1))-1)) a=-((1<<(b-1))-1);
    if (a>((1<<(b-1))-1)) a=((1<<(b-1))-1);
    return a;
}

unsigned char readbyte(FILE *f)
{
  unsigned char res;

  fread(&res, 1, 1, f);
  return res;
}

unsigned short readword(FILE *f)
{
  unsigned char res[2];

  fread(&res, 2, 1, f);
  return (res[0] << 8) | res[1];
}

int playaddress;

int load_sid(const char *sidname, char *mem) {
  FILE *in;
  int dataoffset,loadaddress,initaddress,loadpos,loadend,loadsize;

  // Open SID file
  if (!sidname)
  {
    printf("Error: no SID file specified.\n");
    return -1;
  }

  in = fopen(sidname, "rb");
  if (!in)
  {
    printf("Error: couldn't open SID file.\n");
    return -1;
  }

  // Read interesting parts of the SID header
  fseek(in, 6, SEEK_SET);
  dataoffset = readword(in);
  loadaddress = readword(in);
  initaddress = readword(in);
  playaddress = readword(in);

  fseek(in, 0x7A, SEEK_SET);
  unsigned char second_sid=readbyte(in);
  if ((second_sid&1)==0 && ( (second_sid>=0x42 && second_sid<=0x7E) || (second_sid>=0xE0 && second_sid<=0xFE) )) stereo=1;
  else stereo=0;

  fseek(in, dataoffset, SEEK_SET);
  if (loadaddress == 0)
    loadaddress = readbyte(in) | (readbyte(in) << 8);

  // Load the C64 data
  loadpos = ftell(in);
  fseek(in, 0, SEEK_END);
  loadend = ftell(in);
  fseek(in, loadpos, SEEK_SET);
  loadsize = loadend - loadpos;
  if (loadsize + loadaddress >= 0x10000)
  {
    printf("Error: SID data continues past end of C64 memory.\n");
    fclose(in);
    return -1;
  }
  fread(&mem[loadaddress], loadsize, 1, in);
  fclose(in);
  return initaddress;
}

#define MAX_INSTR 0x100000

volatile int instr;
volatile int last_instr;
unsigned char last_byte;

void SIDwrite(int addr, uint8_t data) {
//    databus[dataindexwrite/databus_N]=data | ((addr<<8)&0x1F00) | ((instr<<16)&0xFF0000);
//    dataindexwrite+=4;
    unsigned char b[4]={0x00,0x7D,255,0};
    while (last_instr-instr>32000) {
        last_instr-=32000;
        serout(b,4);
    }
    b[0]=(last_instr-instr)&255;
    b[1]=(last_instr-instr)>>8;
    b[2]=addr&127;b[3]=data;
    serout(b,4);
    last_instr=instr;
    last_byte=data;
}

int runcpu(m6502_t *cpu, uint64_t *pins, uint8_t *mem) {
    *pins = m6502_tick(cpu, *pins);
    const uint16_t addr = M6502_GET_ADDR(*pins);
    if (*pins & M6502_RW) {
        if ((addr&0xFFE0)==0xD400) {
            M6502_SET_DATA(*pins, last_byte);
        }
        else M6502_SET_DATA(*pins, mem[addr]);
    }
    else {
        if ((addr&0xFFE0)==0xD400) {
            if (stereo) {
                SIDwrite(addr,M6502_GET_DATA(*pins));
            } else {
                SIDwrite(addr|0x40,M6502_GET_DATA(*pins));
            }
        }
        else if ((addr&0xFFE0)==0xD420) {
            SIDwrite(addr,M6502_GET_DATA(*pins));
        }
        else if ((addr&0xFFE0)==0xD500) {
            SIDwrite(addr|0x20,M6502_GET_DATA(*pins));
        }
        else if ((addr&0xFEE0)==0xDE00) {
            SIDwrite(addr|0x20,M6502_GET_DATA(*pins));
        }
        else mem[addr] = M6502_GET_DATA(*pins);
    }
    return 0;
}

void setPC(uint16_t next_pc, m6502_t *cpu, uint64_t *pins, uint8_t *mem) {
    *pins = M6502_SYNC;
    M6502_SET_ADDR(*pins, next_pc);
    M6502_SET_DATA(*pins, mem[next_pc]);
    m6502_set_pc(cpu, next_pc);
}

int open_seriak(char *name) {
    char namefull[100];
    DCB dcbSerialParams = {0};
    COMMTIMEOUTS timeouts = {0};

    if (strlen(name)>80) return -1;
    sprintf(namefull,"\\\\.\\%s",name);

    fprintf(stderr, "Opening serial port...");
    hSerial = CreateFile(
                namefull, GENERIC_READ|GENERIC_WRITE, 0, NULL,
                OPEN_EXISTING, FILE_ATTRIBUTE_NORMAL, NULL );
    if (hSerial == INVALID_HANDLE_VALUE)
    {
            fprintf(stderr, "Error\n");
            return 1;
    }
    else fprintf(stderr, "OK\n");

    dcbSerialParams.DCBlength = sizeof(dcbSerialParams);
    if (GetCommState(hSerial, &dcbSerialParams) == 0)
    {
        fprintf(stderr, "Error getting device state\n");
        CloseHandle(hSerial);
        return 1;
    }

    dcbSerialParams.BaudRate = CBR_115200;
    dcbSerialParams.ByteSize = 8;
    dcbSerialParams.StopBits = ONESTOPBIT;
    dcbSerialParams.Parity = NOPARITY;
    dcbSerialParams.fDtrControl = FALSE;
    dcbSerialParams.fBinary = TRUE;
    if(SetCommState(hSerial, &dcbSerialParams) == 0)
    {
        fprintf(stderr, "Error setting device parameters\n");
        CloseHandle(hSerial);
        return 1;
    }

    // Set COM port timeout settings
    timeouts.ReadIntervalTimeout = MAXDWORD;
    timeouts.ReadTotalTimeoutConstant = 0;
    timeouts.ReadTotalTimeoutMultiplier = 0;
    timeouts.WriteTotalTimeoutConstant = 50;
    timeouts.WriteTotalTimeoutMultiplier = 10;
    if(SetCommTimeouts(hSerial, &timeouts) == 0)
    {
        fprintf(stderr, "Error setting timeouts\n");
        CloseHandle(hSerial);
        return 1;
    }
    return 0;
}
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

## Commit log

2021-04-11 Schematic update for better readability
    [Arduino_AMRSID_tester_dual.brd, Arduino_AMRSID_tester_dual.sch]
2021-04-17 SCH and PCB update
    [Arduino_AMRSID_tester_dual.brd, Arduino_AMRSID_tester_dual.sch]
2021-04-17 Schematic and PCB cleanup, v1.1 Gerbers
    [Arduino_AMRSID_tester_dual.brd, Arduino_AMRSID_tester_dual.sch, Arduino_AMRSID_tester_dual_BOM.xls]
2023-03-07 cputs2 with variable string fix
    [ARMSID_test.ino, sidapi.h]
2024-06-15 ARMSID fw 2.16 compatibility - added switch to enable EXT IN - added switch to lower autodetection values for SID type

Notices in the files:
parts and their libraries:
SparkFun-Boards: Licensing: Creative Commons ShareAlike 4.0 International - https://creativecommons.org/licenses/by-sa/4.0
